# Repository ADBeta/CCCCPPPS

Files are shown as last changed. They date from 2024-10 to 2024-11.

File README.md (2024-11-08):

# Cheap Crappy Constant Current Portable Programmable Power Supply 
## A Power Supply built with a CH32V003

A DIY Programmable Buck/Boost Power Supply, with the following specs:  
* Max Output Voltage  15V
* Max Output Current  1.5A
* Max Output Power    5W

# Usage
## Debug Interface:
This interface is enabled by default when building the firmware. Use `minichlink`
to issue commands listed below

## USB Interface:
Build with `-DCONFIG_USE_USB`
> [!NOTE]
> To be implemented.

## Commands
> [!NOTE]
> Need to improve the command list and handler

- `0` to turn the supply off
- `1-9` to set the target Voltage/Current in multiples of 1000mV/100mA
- `c` to switch to Constant Current Mode 
- `v` to switch to Constant Voltage Mode
- `+` to increase the target Voltage/Current depending on mode, in 50mV/25mA increments
- ~~Konami code makes the unit self distruct.~~ Removed due to misuse.

# Build
```sh
export CH32V003FUN="path/to/ch32v003fun"
make
```

----
(c) 2024
Bogdan Ionescu
ADBeta

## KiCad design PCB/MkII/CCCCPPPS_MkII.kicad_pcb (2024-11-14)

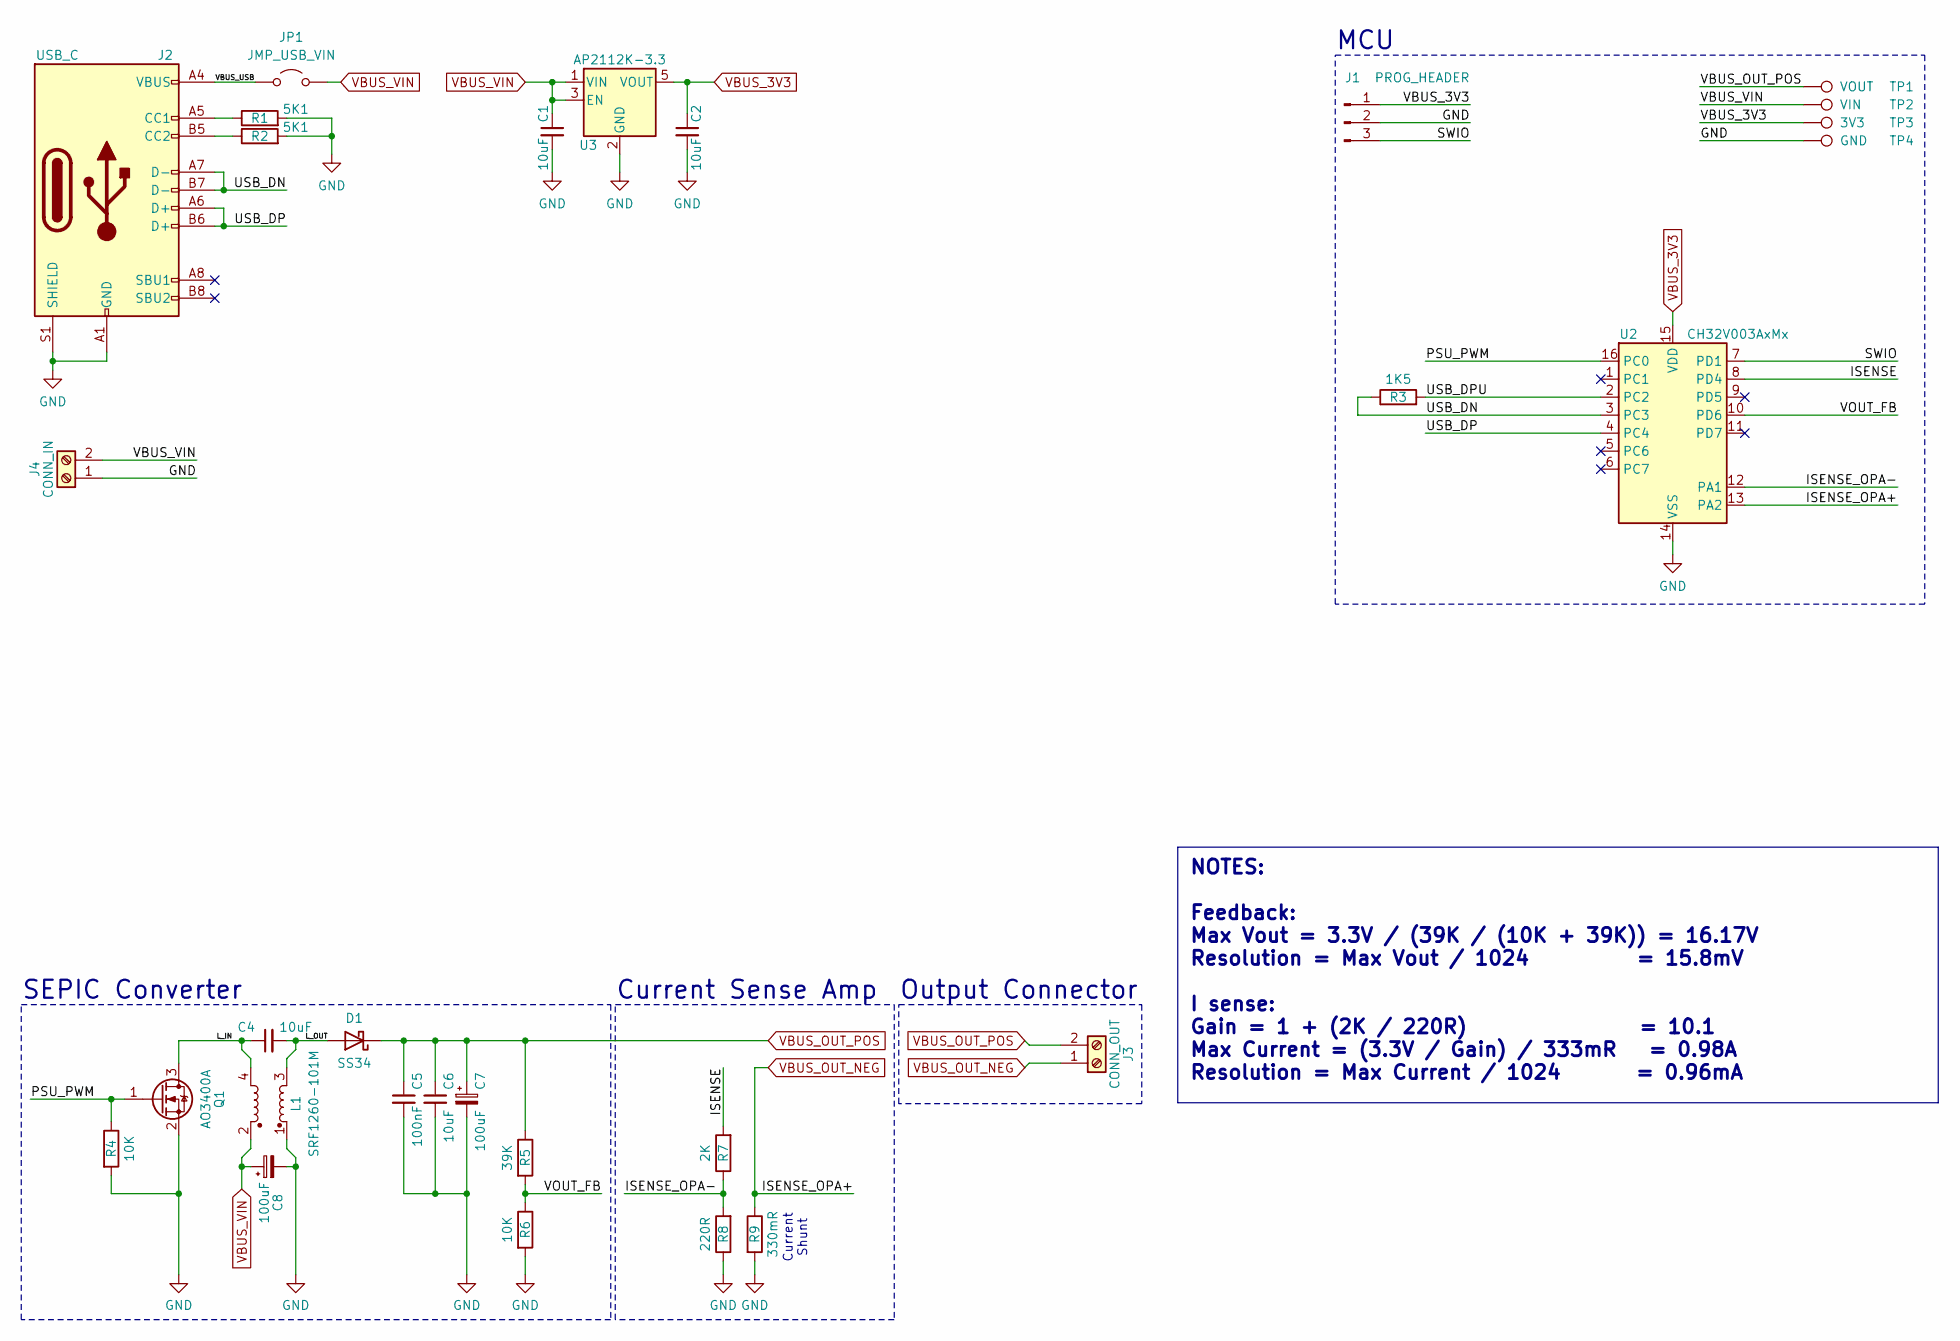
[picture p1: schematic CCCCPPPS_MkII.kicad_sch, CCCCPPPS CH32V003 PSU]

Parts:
C1, C2, C4, C6: 10uF; C_0805_2012Metric
C5: 100nF; C_0805_2012Metric
C7, C8: 100uF; CP_Elec_6.3x5.2
D1: SS34; D_SMA
J1: PROG_HEADER; PinHeader_1x03_P2.54mm_Vertical
J2: USB_C; USB_C_Receptacle_G-Switch_GT-USB-7010ASV
J3: CONN_OUT; PCB_Terminal_Block_2-P3.5
J4: CONN_IN; PCB_Terminal_Block_2-P3.5
JP1: JMP_USB_VIN; SolderJumper-2_P1.3mm_Open_RoundedPad1.0x1.5mm
L1: SRF1260-101M; L_Bourns_SRF1260
Q1: AO3400A; SOT-23
R1, R2: 5K1; R_0805_2012Metric
R3: 1K5; R_0805_2012Metric
R4, R6: 10K; R_0805_2012Metric
R5: 39K; R_0805_2012Metric
R7: 2K; R_0805_2012Metric
R8: 220R; R_0805_2012Metric
R9: 330mR; R_2512_6332Metric_Pad1.40x3.35mm_HandSolder
TP1: VOUT; TestPoint_Pad_D1.5mm
TP2: VIN; TestPoint_Pad_D1.5mm
TP3: 3V3; TestPoint_Pad_D1.5mm
TP4: GND; TestPoint_Pad_D1.5mm
U2: CH32V003AxMx; SOP-16_3.9x9.9mm_P1.27mm
U3: AP2112K-3.3; SOT-23-5

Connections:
/ISENSE: R7.2, U2.8 (PD4)
/ISENSE_OPA-: R7.1, R8.2, U2.12 (PA1)
/L_IN: C4.1, L1.4, Q1.3 (D)
/L_OUT: C4.2, D1.2 (A), L1.3
/PSU_PWM: Q1.1 (G), R4.1, U2.16 (PC0)
/SWIO: J1.3, U2.7 (PD1)
/USB_DN: J2.A7 (D-), J2.B7 (D-), R3.1, U2.3 (PC3)
/USB_DP: J2.A6 (D+), J2.B6 (D+), U2.4 (PC4)
/USB_DPU: R3.2, U2.2 (PC2)
/VBUS_USB: J2.A4 (VBUS), J2.A9 (VBUS), J2.B4 (VBUS), J2.B9 (VBUS), JP1.1 (A)
/VOUT_FB: R5.2, R6.1, U2.10 (PD6)
GND: C1.2, C2.2, C5.2, C6.2, C7.2, C8.2, J1.2, J2.A1 (GND), J2.A12 (GND), J2.B1 (GND), J2.B12 (GND), J2.S1 (SHIELD), J4.1, L1.1, Q1.2 (S), R1.2, R2.2, R4.2, R6.2, R8.1, R9.2, TP4.1, U2.14 (VSS), U3.2 (GND)
unnamed: J2.A5 (CC1), R1.1
unnamed: J2.B5 (CC2), R2.1
VBUS_3V3: C2.1, J1.1, TP3.1, U2.15 (VDD), U3.5 (VOUT)
VBUS_OUT_NEG: J3.1, R9.1, U2.13 (PA2)
VBUS_OUT_POS: C5.1, C6.1, C7.1, D1.1 (K), J3.2, R5.1, TP1.1
VBUS_VIN: C1.1, C8.1, J4.2, JP1.2 (B), L1.2, TP2.1, U3.1 (VIN), U3.3 (EN)

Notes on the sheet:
NOTES: Feedback: Max Vout = 3.3V / (39K / (10K + 39K)) = 16.17V Resolution = Max Vout / 1024 = 15.8mV I sense: Gain = 1 + (2K / 220R) = 10.1 Max Current = (3.3V / Gain) / 333mR = 0.98A Resolution = Max Current / 1024 = 0.96mA
MCU
Output Connector
Current Shunt
SEPIC Converter
Current Sense Amp

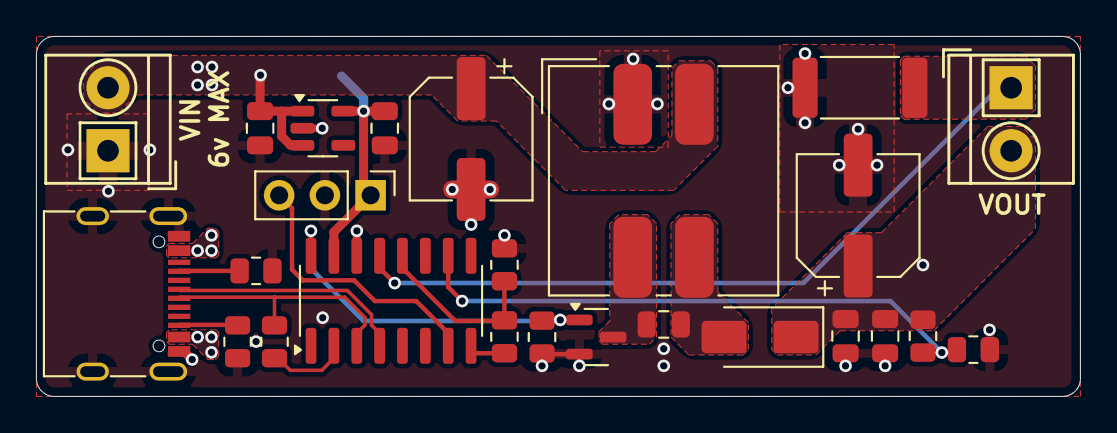
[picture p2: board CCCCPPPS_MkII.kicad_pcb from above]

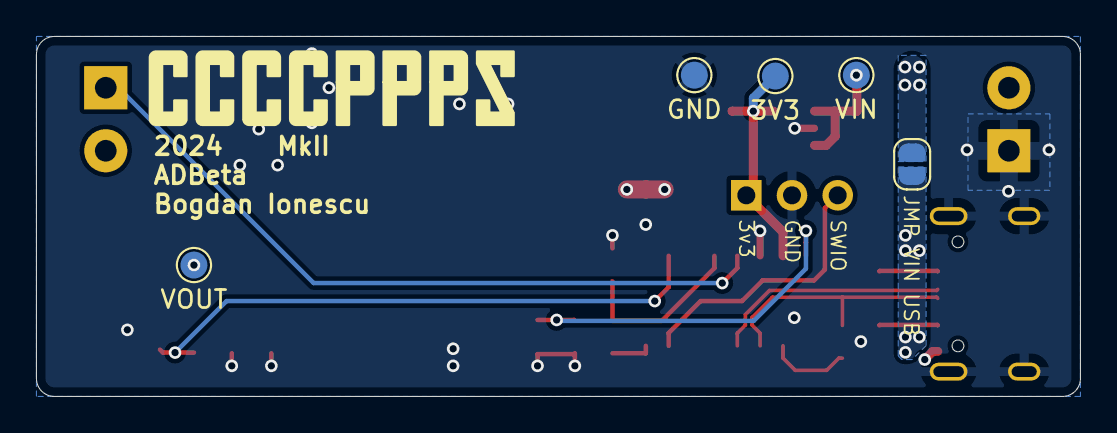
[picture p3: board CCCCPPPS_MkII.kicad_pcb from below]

Board: 2 copper layers, 58.0 x 20.0 mm, 30 parts (5 on the bottom side), 18 nets.

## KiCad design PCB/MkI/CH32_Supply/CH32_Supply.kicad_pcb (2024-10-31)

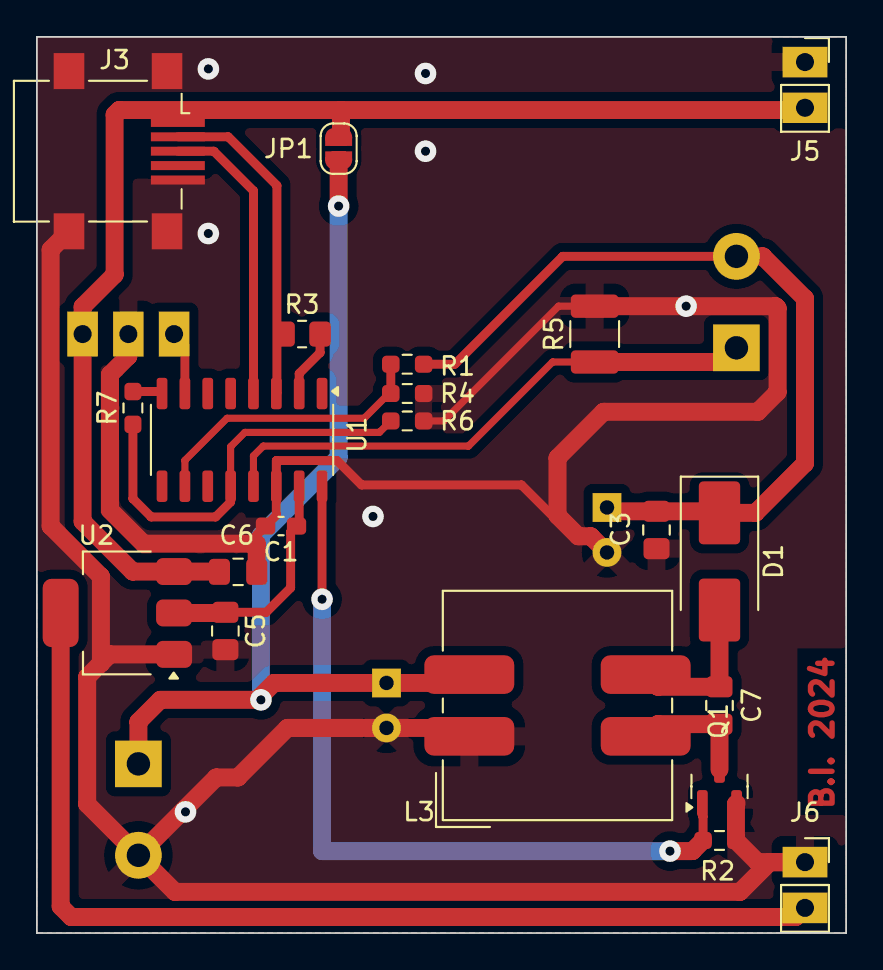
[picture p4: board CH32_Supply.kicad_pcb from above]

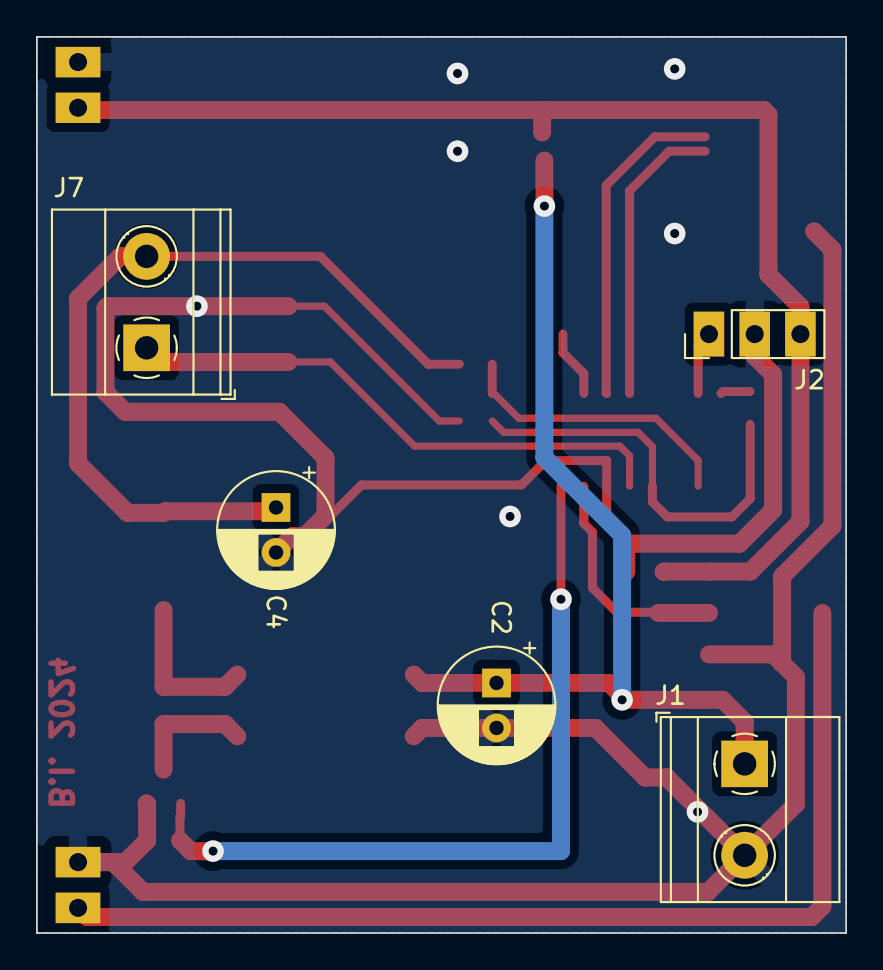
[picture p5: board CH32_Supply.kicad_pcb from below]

Board: 2 copper layers, 45.0 x 49.8 mm, 26 parts (5 on the bottom side), 16 nets.

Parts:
C1: 0.1uF; C_0603_1608Metric_Pad1.08x0.95mm_HandSolder
C2: 100uF; CP_Radial_D6.3mm_P2.50mm
C3, C6, C7: 10uF; C_0805_2012Metric_Pad1.18x1.45mm_HandSolder
C4: 100uF 25V; CP_Radial_D6.3mm_P2.50mm
C5: 1uF; C_0805_2012Metric_Pad1.18x1.45mm_HandSolder
D1: B2100-13-F; D_SMB_Handsoldering
J1, J7: Screw_Terminal_01x02; TerminalBlock_Phoenix_MKDS-1,5-2-5.08_1x02_P5.08mm_Horizont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
J2: PROG; PinHeader_1x03_P2.54mm_Vertical
J3: USB_B_Mini; USB_Mini-B_Lumberg_2486_01_Horizontal
J5, J6: Conn_01x02; PinSocket_1x02_P2.54mm_Vertical
JP1: SolderJumper_2_Open; SolderJumper-2_P1.3mm_Open_RoundedPad1.0x1.5mm
L3: SRF1260-101M; L_Bourns_SRF1260
Q1: AO3400A; SOT-23
R1: 39k; R_0603_1608Metric_Pad0.98x0.95mm_HandSolder
R2, R4: 10k; R_0603_1608Metric_Pad0.98x0.95mm_HandSolder
R3: 1K5; R_0805_2012Metric_Pad1.20x1.40mm_HandSolder
R5: 333mΩ; R_1210_3225Metric_Pad1.30x2.65mm_HandSolder
R6: 220R; R_0603_1608Metric_Pad0.98x0.95mm_HandSolder
R7: 2k; R_0603_1608Metric_Pad0.98x0.95mm_HandSolder
U1: CH32V003A4M6; SO-16_3.9x9.9mm_P1.27mm
U2: AZ1117-3.3; SOT-223-3_TabPin2

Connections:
+3V3: C1.1, C5.1, J6.2, U1.15 (VDD), U2.2 (VO)
+5V: C6.1, J2.3, J3.1 (VBUS), J5.2, JP1.2 (B), U2.3 (VI)
/VOUT+: C3.1, C4.1, D1.1 (K), J7.2, R1.1
GND: C1.2, C2.2, C3.2, C4.2, C5.2, C6.2, J1.2, J2.2, J3.5 (GND), J3.6 (Shield), J5.1, J6.1, L3.1, Q1.2 (S), R2.2, R4.2, R5.2, R6.1, U1.14 (vss), U2.1 (GND)
unnamed: C7.2, D1.2 (A), L3.3
unnamed: C7.1, L3.4, Q1.3 (D)
PA1: R6.2, R7.1, U1.12 (PA1_A1_T1CH2_OSCI)
PA2: J7.1, R5.1, U1.13 (PA2_A0_T1CH2N_OSCO)
PC0: Q1.1 (G), R2.1, U1.16 (PC0_T2CH3)
PC2: R3.1, U1.2 (PC2_SCL)
PC3: J3.2 (D-), R3.2, U1.3 (PC3)
PC4: J3.3 (D+), U1.4 (PC4_A2_T1CH4)
PD4: R7.2, U1.8 (PD4_A7_T2AETR2)
PD6: R1.2, R4.1, U1.10 (PD6_A6_UART_RX)
SWIO: J2.1, U1.7 (SWIO&PD1_T1CH3N)
VPP: C2.1, J1.1, JP1.1 (A), L3.2

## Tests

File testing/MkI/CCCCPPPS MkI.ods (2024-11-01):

V | Vin | Ain | Vread | Aread | Vout | Aout | Pin | Pout-read | Pout | CoP-read | CoP | Verr % | Aerr %
1 | 5.2 | 0.026 | 0.99 | 0.044 | 0.964 | 0.043 | 0.1352 | 0.04356 | 0.041452 | 32.2189349112426 | 30.6597633136095 | 2.70% | 2.33%
2 | 5.19 | 0.056 | 1.99 | 0.09 | 1.968 | 0.0885 | 0.29064 | 0.1791 | 0.174168 | 61.6226259289843 | 59.925681255161 | 1.12% | 1.69%
3 | 5.175 | 0.11 | 2.99 | 0.137 | 2.987 | 0.1345 | 0.56925 | 0.40963 | 0.4017515 | 71.959595959596 | 70.5755819060167 | 0.10% | 1.86%
4 | 5.155 | 0.18 | 4 | 0.183 | 3.958 | 0.178 | 0.9279 | 0.732 | 0.704524 | 78.8878111865503 | 75.9267162409742 | 1.06% | 2.81%
5 | 5.129 | 0.271 | 4.99 | 0.228 | 4.94 | 0.222 | 1.389959 | 1.13772 | 1.09668 | 81.852774074631 | 78.9001689977906 | 1.01% | 2.70%
6 | 5.095 | 0.39 | 5.99 | 0.275 | 5.939 | 0.267 | 1.98705 | 1.64725 | 1.585713 | 82.8992727913238 | 79.8023703480033 | 0.86% | 3.00%
7 | 5.05 | 0.537 | 7 | 0.322 | 6.96 | 0.312 | 2.71185 | 2.254 | 2.17152 | 83.1166915574239 | 80.0752253996349 | 0.57% | 3.21%
8 | 5.005 | 0.705 | 7.99 | 0.365 | 7.89 | 0.354 | 3.528525 | 2.91635 | 2.79306 | 82.6506826506827 | 79.1565880927583 | 1.27% | 3.11%
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

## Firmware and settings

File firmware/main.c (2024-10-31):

//------------------------------------------------------------------------------
//       Filename: main.c
//------------------------------------------------------------------------------
//       Bogdan Ionescu (c) 2024
//------------------------------------------------------------------------------
//       Purpose : Application entry point
//------------------------------------------------------------------------------
//       Notes : None
//------------------------------------------------------------------------------

//------------------------------------------------------------------------------
// Module includes
//------------------------------------------------------------------------------
#include <inttypes.h>
#include <stdbool.h>

#include "RingBuffer.h"
#include "boost.h"
#include "ch32v003fun.h"
#include "log.h"
#include "rv003usb.h"

//------------------------------------------------------------------------------
// Module constant defines
//------------------------------------------------------------------------------

#define TAG "main"

#define array_size(x) (sizeof(x) / sizeof(x[0]))
//------------------------------------------------------------------------------
// External variables
//------------------------------------------------------------------------------

//------------------------------------------------------------------------------
// External functions
//------------------------------------------------------------------------------

//------------------------------------------------------------------------------
// Module type definitions
//------------------------------------------------------------------------------

//------------------------------------------------------------------------------
// Module static variables
//------------------------------------------------------------------------------
static volatile uint32_t s_systickCount = 0;
static RingBuffer_t printRingBuffer = {0};

//------------------------------------------------------------------------------
// Module static function prototypes
//------------------------------------------------------------------------------
static void SysTick_Init(void);
static void WDT_Init(uint16_t reload_val, uint8_t prescaler);
static void WDT_Pet(void);

//------------------------------------------------------------------------------
// Module externally exported functions
//------------------------------------------------------------------------------

/**
 * @brief  Application entry point
 * @param  None
 * @return None
 */
int main(void)
{
    SystemInit();

#if FUNCONF_USE_DEBUGPRINTF
    WaitForDebuggerToAttach();
#endif

    SysTick_Init();

#ifdef CONFIG_USE_USB
    static volatile uint8_t printBuffer[64] = {0};
    (void)RingBuffer_Init(&printRingBuffer, (uint8_t *)printBuffer, array_size(printBuffer));
    usb_setup();
#endif

    LOG_Init(eLOG_LEVEL_DEBUG, (uint32_t *)&s_systickCount);

    BoostPWM_Init();

#if 0

    for (size_t i = 1000; i < 5001; i += 200)
    {
        BoostPWM_SetVoltageTarget(i);
        LOGD(TAG, "Target: %dmV", i);
        Delay_Ms(100);
    }
#endif

    WDT_Init(0x0FFF, IWDG_Prescaler_128);

    static uint32_t voltage = 0;
    static uint32_t current = 0;
    static uint32_t power = 0;
    static uint32_t voltageTarget = 0;
    static uint32_t currentLimit = 0;
    static bool ccMode = false;

    while (1)
    {
        WDT_Pet();

        int c = getchar();

        switch (c)
        {
            case '0':
                BoostPWM_SetVoltageTarget(0);
                BoostPWM_SetCurrentLimit(0);
                voltageTarget = 0;
                currentLimit = 0;
                break;
            case '+':
            case '=':
                if (ccMode)
                {
                    currentLimit += 25;
                    BoostPWM_SetCurrentLimit(currentLimit);
                }
                else
                {
                    voltageTarget += 50;
                    BoostPWM_SetVoltageTarget(voltageTarget);
                }
                break;
            case '-':
                if (ccMode)
                {
                    currentLimit -= 25;
                    BoostPWM_SetCurrentLimit(currentLimit);
                }
                else
                {
                    voltageTarget -= 50;
                    BoostPWM_SetVoltageTarget(voltageTarget);
                }
                break;
            case -1:
                voltage = BoostPWM_GetVoltageMillivolts();
                current = BoostPWM_GetCurrentMilliamps();
                power = voltage * current;
                LOGI(TAG, "CC: %d, Voltage: %dmV, Current: %dmA, Power: %dmW",
                     ccMode,
                     voltage,
                     current,
                     power / 1000);
                break;
            case 'c':
                ccMode = true;
                break;
            case 'v':
                ccMode = false;
                currentLimit = 0;
                BoostPWM_SetCurrentLimit(0);
                break;
            default:
                if (c <= '0' || c > '9') break;
                if (ccMode)
                {
                    currentLimit = (c - '0') * 100;
                    BoostPWM_SetCurrentLimit(currentLimit);
                }
                else
                {
                    voltageTarget = (c - '0') * 1000;
                    BoostPWM_SetVoltageTarget(voltageTarget);
                }
                break;
        }

        Delay_Ms(100);
    }
}

#if !FUNCONF_USE_DEBUGPRINTF

/**
 * @brief  Write string to console
 * @param      fd - the file descriptor(ignored)
 * @param[in]  buf - the buffer
 * @param      size - buffer size in bytes
 * @return the number of bytes written
 */
int _write(int fd, const char *buf, int size)
{
    (void)fd;
    (void)RingBuffer_Put(&printRingBuffer, (uint8_t *)buf, size);
    return size;
}
#endif

//------------------------------------------------------------------------------
// Module static functions
//------------------------------------------------------------------------------

/**
 * @brief  Enable the SysTick module
 * @param  None
 * @return None
 */
static void SysTick_Init(void)
{
    // Disable default SysTick behavior
    SysTick->CTLR = 0;

    // Enable the SysTick IRQ
    NVIC_EnableIRQ(SysTicK_IRQn);

    // Set the tick interval to 1ms for normal op
    SysTick->CMP = (FUNCONF_SYSTEM_CORE_CLOCK / 1000) - 1;

    // Start at zero
    SysTick->CNT = 0;
    s_systickCount = 0;

    // Enable SysTick counter, IRQ, HCLK/1
    SysTick->CTLR = SYSTICK_CTLR_STE | SYSTICK_CTLR_STIE | SYSTICK_CTLR_STCLK;
}

/**
 * @brief  Initialize the watchdog timer
 * @param reload_val - the value to reload the counter with
 * @param prescaler - the prescaler to use
 * @return None
 */
static void WDT_Init(uint16_t reload_val, uint8_t prescaler)
{
    IWDG->CTLR = 0x5555;
    IWDG->PSCR = prescaler;

    IWDG->CTLR = 0x5555;
    IWDG->RLDR = reload_val & 0xfff;

    IWDG->CTLR = 0xCCCC;
}

/**
 * @brief  Pet the watchdog timer
 * @param  None
 * @return None
 */
static void WDT_Pet(void)
{
    IWDG->CTLR = 0xAAAA;
}

/**
 * @brief  SysTick interrupt handler
 * @param  None
 * @return None
 * @note   __attribute__((interrupt)) syntax is crucial!
 */
void SysTick_Handler(void) __attribute__((interrupt));
void SysTick_Handler(void)
{
    // Set the next interrupt to be in 1/1000th of a second
    SysTick->CMP += (FUNCONF_SYSTEM_CORE_CLOCK / 1000);

    // Clear IRQ
    SysTick->SR = 0;

    // Update counter
    s_systickCount++;
}

/**
 * @brief  Handle USB user in requests
 * @param  e - the endpoint
 * @param  scratchpad - the scratchpad buffer
 * @param  endp - the endpoint number
 * @param  sendtok - the token to send
 * @param  ist - the internal state
 * @return None
 * @note usb_hande_interrupt_in is OBLIGATED to call usb_send_data or usb_send_empty.
 */
void usb_handle_user_in_request(struct usb_endpoint *e, uint8_t *scratchpad, int endp, uint32_t sendtok, struct rv003usb_internal *ist)
{
    if (endp == 3)
    {
        size_t bytes = RingBuffer_Peek(&printRingBuffer);
        if (bytes > 7)
        {
            static uint8_t c[8];
            if (eRING_BUFFER_STATUS_SUCCESS == RingBuffer_Get(&printRingBuffer, c, 8, &bytes))
            {
                usb_send_data(c, 8, 0, sendtok);
                return;
            }
        }
    }
    // If it's a control transfer, don't send anything.
    usb_send_empty(sendtok);
}

/**
 * @brief  Handle USB control messages
 * @param  e - the endpoint
 * @param  s - the URB
 * @param  ist - the internal state
 * @return None
 */
void usb_handle_other_control_message(struct usb_endpoint *e, struct usb_urb *s, struct rv003usb_internal *ist)
{
    LogUEvent(SysTick->CNT, s->wRequestTypeLSBRequestMSB, s->lValueLSBIndexMSB, s->wLength);
    e->opaque = (uint8_t *)1;
}

/**
 * @brief  Handle USB user data
 * @param      e - the endpoint
 * @param      current_endpoint - the current endpoint
 * @param[in]  data - the data
 * @param      len - the length
 * @param      ist - the internal state
 * @return None
 */
void usb_handle_user_data(struct usb_endpoint *e, int current_endpoint, uint8_t *data, int len, struct rv003usb_internal *ist)
{
    LogUEvent(SysTick->CNT, 0xffffffff, current_endpoint, len);
    printf("Got %d bytes\r\n", len);
}

static uint8_t newByte = 0;
static uint32_t count = 0;
static uint32_t countLast = 0;

/**
 * @brief  Debugger input handler
 * @param  numbytes - the number of bytes received
 * @param  data - the data (8 bytes)
 * @return None
 */
void handle_debug_input(int numbytes, uint8_t *data)
{
    newByte = data[0];
    count += numbytes;
}

/**
 * @brief  Get the next character from the debugger
 * @param  None
 * @return the next character or -1 if no character is available
 * @note   This function will block for up to 100ms waiting for a character
 */
int getchar(void)
{
    const uint32_t timeout = 100;
    const uint32_t end = s_systickCount + timeout;
    while (count == countLast && (s_systickCount < end))
    {
        poll_input();
        putchar(0);
    }

    if (count == countLast)
    {
        return -1;
    }

    countLast = count;
    return newByte;
}

//------------------------------------------------------------------------------
//------------------------------------------------------------------------------
//------------------------------------------------------------------------------

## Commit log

2024-10-31 Reformat directory tree
    [CH32_Supply.kicad_pcb, CH32_Supply.kicad_sch]
2024-11-01 MkII PCB Started
    [CCCCPPPS MkI.ods, CCCCPPPS_MkII.kicad_pcb, CCCCPPPS_MkII.kicad_sch]
2024-11-08 MkII PCB Update
    [CCCCPPPS_MkII.kicad_pcb, CCCCPPPS_MkII.kicad_sch]
2024-11-09 PCB Near final
    [CCCCPPPS_MkII.kicad_pcb, CCCCPPPS_MkII.kicad_sch]
2024-11-14 Full Refactor
    [CCCCPPPS_MkII.kicad_pcb, CCCCPPPS_MkII.kicad_sch]
